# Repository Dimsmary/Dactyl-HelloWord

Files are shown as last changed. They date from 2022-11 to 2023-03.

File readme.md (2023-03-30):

# 引言

嗨，这是一个使用了瀚文HelloWord固件的Dactyl人体工程学键盘，其继承了瀚文键盘的基本功能（按键、RGB灯效），支持热插拔，并使用了Dactyl生成器所生成的外壳。

为了最大程度适配瀚文固件所产生的一些设计，导致本项目的复刻难度可能较高，详细情况将在后续内容提及。

# 致谢、参考项目

非常感谢键盘爱好者的无私奉献，下面是本项目继承、参考的项目：

- [peng-zhihui-HelloWord-Keyboard](https://github.com/peng-zhihui/HelloWord-Keyboard)

  瀚文键盘

- [ibnuda-dactyl-keboard](https://github.com/ibnuda/dactyl-keyboard)

  dactyl外壳生成器

- [yejianfengblue-dactyl-generator-demo](https://github.com/yejianfengblue/dactyl-generator-demo)

  dactyl外壳生成器在各参数下的demo

# 文件结构

- 3Dmodel

  该目录下存放了3D模型文件，其中包括了dactyl外壳生成器的json配置文件、OpenSCAD源文件、用于固定PCB的SolidWorks工程文件以及最终导出，能够直接进行3D打印的STL文件。

- Firmware

  该目录下存放了修改后的瀚文键盘固件工程文件、固件（release文件夹下）。

- PCB

  该目录下存放了使用LCEDA绘制的PCB原理图、Layout，以及能够直接用于PCB制造的Gerber文件。

# 构建指南

## 电路构建

本项目的PCB一共包括三块：轴板（Keyboard），主控板（LeftBoard）、扩展板（RightBoard）。

由于Dactyl的异形结构（每个轴都不在一个平面上），按键轴的安装并不能用一块PCB完成。在其他的Dactyl项目中，轴与轴之间的连接通过手工飞线实现。

### 轴板

但为了继承瀚文键盘的大部分功能，使用飞线的方案可能导致较大的飞线数量，故本项目采用了每个按键使用单独一块PCB的方案。每块PCB上焊有RGB灯珠、轴座以及FPC排线连接座，PCB之间以及与主控板的连接通过FPC软排线实现。

为了节省打板费用，我将25个按键PCB拼板到了一个10x10cm的PCB上。

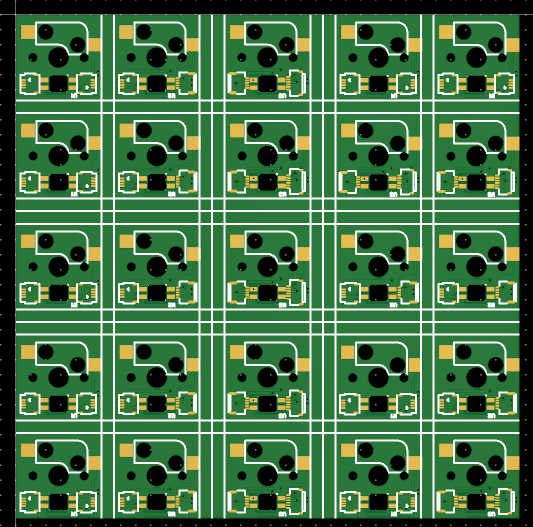
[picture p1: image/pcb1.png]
pcb1


注意，这25个按键PCB并不是一样的，而是分为了3号PCB、2号PCB以及1号PCB。

对于1号PCB，其右边的FPC连接座为6P，从上至下的线序为（KEY1/KEY2/KEY3/GND/DIN/5V），而左边的FPC连接座为5P，从上至下的线序为（KEY2/KEY3/GND/DOUT/5V）。右边的6P座直接与主控连接，负责获取RGB灯珠的电源、信号以及传递按键连接。左边的5P座与2号PCB的5P座连接，将RGB电源、信号传递以及按键连接线的中继。

对于2号PCB，其右边的FPC连接座为5P，即与1号PCB相连。左边的FPC连接座为4P，从上至下的线序为（KEY2/KEY3/GND/DOUT/5V），与3号PCB相连。

对于3号PCB，其右边4P座与2号相连，左边的4P座定义为（GND/DOUT/DOUT/GND），即将RGB灯珠的输出信号传回至主控板。

1、2、3号PCB构成一个按键PCB组，由于RGB灯珠的信号是逐级传递的，故每个PCB组的3号PCB需要传回主控板，主控板再走线将信号输出至下一个PCB组的RGB信号输入。

每个PCB单元可以沿着白线使用铁皮剪剪开获得独立的PCB。

注意1：建议先进行剪裁再进行焊接，如果先焊接在剪裁的话可能会导致焊接在PCB上的元件损坏。

注意2：轴板的焊接工作量巨大，如果经济实力允许，建议使用SMT服务。

注意3：4P座的排线连接方向是反的，但不影响使用，如在意，可自行调整。

### 主控板

主控板的电路完全参考瀚文键盘，在移位寄存器的数量上进行了删减。其上一共有四个连接器：RJ45（负责给扩展板提供电源和传递信号）、Type-C（连接电脑）、SWD（程序下载接口）、UART（预留接口，可进行瀚文键盘其他功能的扩展）。

主控板被安装在左手键盘。

### 扩展板

扩展板上仅有移位寄存器、连接座以及LDO，其与主控板的连接通过RJ45实现。

注意：在USB连接上电脑前，需要保证主控板和扩展版的连接通畅，如果两块板之间的连接断开的话，由于单片机缺少移位寄存器的回传信号，会导致按键误判（表现为随机输出按键信息至电脑）。

## 外壳构建

OpenSCAD文件夹：其内包括了Dactyl外壳的OpenSCAD源文件以及生成器的Json文件。将Json文件导入外壳生成器的网站可以加载我的设置并进行修改。

SolidWorks文件夹：其内包括了承载电路板的结构件。

STL文件夹：其内的STL文件可直接进行3D打印。

注意1：由于空间问题，承载电路板的结构件与外壳之间的卡口处需要打磨。

注意2：由于设计问题，两块电路板的底面需要是平整的，需要使用锉刀锉去凸起，否则无法安装仅承载电路板的结构件。

## 固件上传

通过STLINK或其他下载器，将Firmware>Release中的bin文件上传至STM32即可，若需要进行键位的修改，可自行编译HelloWord-keyborad-fw中的文件。

# 友情项目

这里记录了其他爱好者基于本项目进行改进的项目：

https://github.com/Byvm815/Dactyl-HelloWord

# 更新日志

2022-11-04：

readme基本完成，但还需要完善。

2022-03-30：

readme添加友情项目

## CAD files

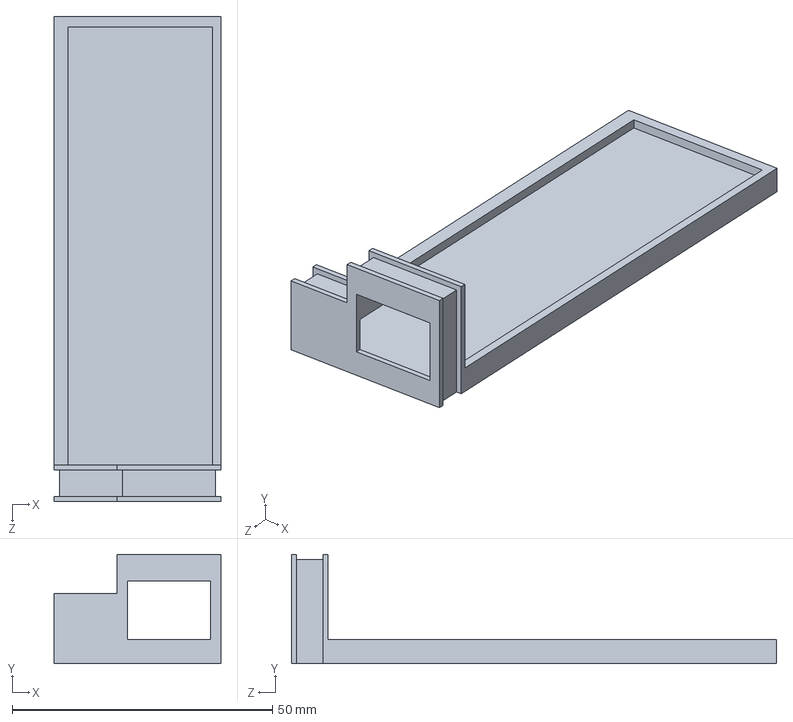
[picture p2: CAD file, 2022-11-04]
3Dmodel/SolidWorks/right_board_support.SLDPRT
32.0 x 21.0 x 93.1 mm

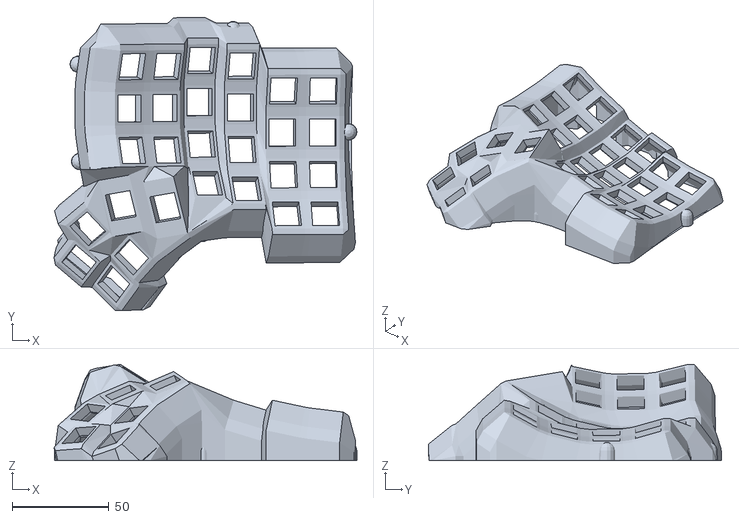
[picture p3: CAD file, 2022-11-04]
3Dmodel/STL/manuform-case-right-2022.08.30-12.28.57.stl
156.7 x 151.5 x 49.9

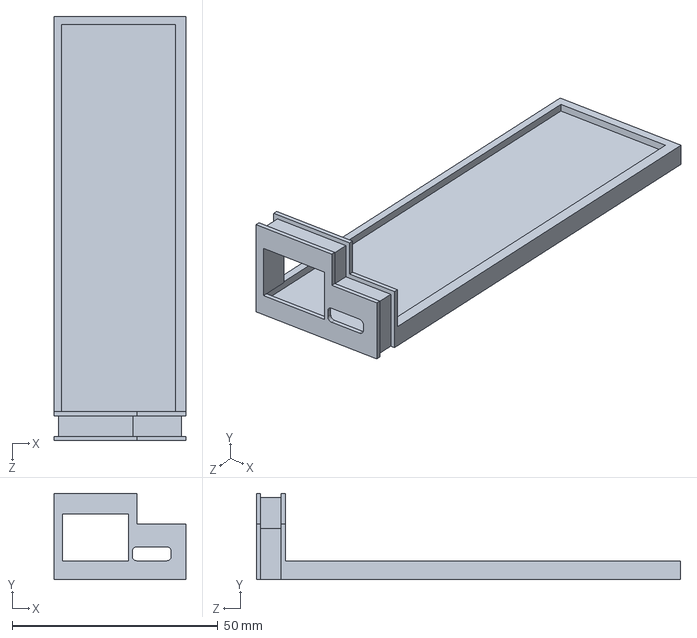
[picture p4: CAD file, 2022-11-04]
3Dmodel/SolidWorks/left_board_support.SLDPRT
32.0 x 21.0 x 103.1 mm

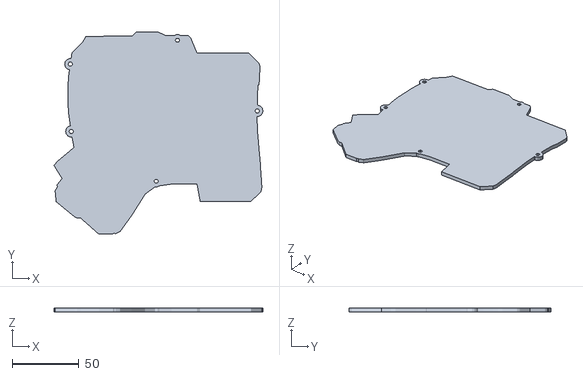
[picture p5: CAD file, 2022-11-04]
3Dmodel/STL/manuform-plate-right-2022.08.30-12.28.55.stl
156.4 x 151.4 x 3.00

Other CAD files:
3Dmodel/STL/manuform-case-left-2022.08.30-12.29.05.stl
3Dmodel/STL/manuform-plate-left-2022.08.30-12.29.03.stl
3Dmodel/OpenSCAD/manuform-case-left-2022.08.30-12.29.05.scad
3Dmodel/OpenSCAD/manuform-case-right-2022.08.30-12.28.57.scad
3Dmodel/OpenSCAD/manuform-plate-2022.08.30-12.28.55.scad
3Dmodel/OpenSCAD/manuform-plate-2022.08.30-12.29.03.scad
3Dmodel/STL/left_board_support.STL
3Dmodel/STL/right_board_support.STL

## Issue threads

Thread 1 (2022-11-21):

关于轴板在键盘外壳上的分布问题

A-new-b, 2022-11-21:
您好，我对您的键盘方案十分感兴趣，目前正在按照您提供的方案制作键盘，但我目前遇见了一个问题。

您提到了轴板有三种类型，分别为U1,U2,U3,对应4pin,5pin,6pin,在外壳上，我并不清楚单独的一个格子对应的是u1,u2还是u3,
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

我确实已经反复看过您的视频和立创文件，目前卡在了这一步，希望您能给我一个解答，感激不尽！

Dimsmary, 2022-11-21:
不好意思，轴板的连接比较复杂，文档还有待完善。
左手的轴板连接如图所示，如果有任何疑问欢迎继续提出。
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

Dimsmary, 2022-11-21:
不好意思，轴板的连接比较复杂，文档还有待完善。
左手的轴板连接如图所示，右手轴板排布基本相同，如果有任何疑问欢迎继续提出。
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

A-new-b, 2022-11-21:
非常感谢，我参照原理图和您的轴板后基本明白了

Closed 2022-11-21.

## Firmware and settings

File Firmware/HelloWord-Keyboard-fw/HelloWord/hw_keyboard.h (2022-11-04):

#ifndef HELLO_WORD_KEYBOARD_FW_HW_KEYBOARD_H
#define HELLO_WORD_KEYBOARD_FW_HW_KEYBOARD_H

#include "spi.h"


class HWKeyboard
{
public:
    explicit HWKeyboard(SPI_HandleTypeDef* _spi) :
        spiHandle(_spi)
    {
        scanBuffer = &spiBuffer[1];

        // Enable 74HC165 clock
        HAL_GPIO_WritePin(CE_GPIO_Port, CE_Pin, GPIO_PIN_RESET);
    }


    static const uint8_t IO_NUMBER = 11 * 8; // Used 11 pcs 74HC165
    static const uint8_t KEY_NUMBER = 82;
    static const uint8_t TOUCHPAD_NUMBER = 6;
    static const uint8_t LED_NUMBER = 104;
    static const uint8_t KEYMAP_NUM = 5;
    static const uint16_t KEY_REPORT_SIZE = 1 + 16;
    static const uint16_t RAW_REPORT_SIZE = 1 + 32;
    static const uint16_t HID_REPORT_SIZE = KEY_REPORT_SIZE + RAW_REPORT_SIZE;

    enum KeyCode_t : int16_t
    {
        /*------------------------- HID report data -------------------------*/
        LEFT_CTRL = -8, LEFT_SHIFT = -7, LEFT_ALT = -6, LEFT_GUI = -5,
        RIGHT_CTRL = -4, RIGHT_SHIFT = -3, RIGHT_ALT = -2, RIGHT_GUI = -1,

        RESERVED = 0, ERROR_ROLL_OVER, POST_FAIL, ERROR_UNDEFINED,
        A, B, C, D, E, F, G, H, I, J, K, L, M,
        N, O, P, Q, R, S, T, U, V, W, X, Y, Z,
        NUM_1/*1!*/, NUM_2/*2@*/, NUM_3/*3#*/, NUM_4/*4$*/, NUM_5/*5%*/,
        NUM_6/*6^*/, NUM_7/*7&*/, NUM_8/*8**/, NUM_9/*9(*/, NUM_0/*0)*/,
        ENTER, ESC, BACKSPACE, TAB, SPACE,
        MINUS/*-_*/, EQUAL/*=+*/, LEFT_U_BRACE/*[{*/, RIGHT_U_BRACE/*]}*/,
        BACKSLASH/*\|*/, NONE_US/**/, SEMI_COLON/*;:*/, QUOTE/*'"*/,
        GRAVE_ACCENT/*`~*/, COMMA/*,<*/, PERIOD/*.>*/, SLASH/*/?*/,
        CAP_LOCK, F1, F2, F3, F4, F5, F6, F7, F8, F9, F10, F11, F12,
        PRINT, SCROLL_LOCK, PAUSE, INSERT, HOME, PAGE_UP, DELETE, END, PAGE_DOWN,
        RIGHT_ARROW, LEFT_ARROW, DOWN_ARROW, UP_ARROW, PAD_NUM_LOCK,
        PAD_SLASH, PAD_ASTERISK, PAD_MINUS, PAD_PLUS, PAD_ENTER,
        PAD_NUM_1, PAD_NUM_2, PAD_NUM_3, PAD_NUM_4, PAD_NUM_5,
        PAD_NUM_6, PAD_NUM_7, PAD_NUM_8, PAD_NUM_9, PAD_NUM_0,
        PAD_PERIOD = 99, // followed with 20 bits 0, total 16 Bytes report data
        /*------------------------- HID report data -------------------------*/

//      /*-------------------------- Virtual keys ---------------------------*/
//      EXECUTE = 116,
//      HELP, MENU, SELECT, STOP, AGAIN, UNDO, CUT, COPY, PASTE, FIND, MUTE,
//      VOLUME_UP, VOLUME_DOWN,
//      /*-------------------------- Virtual keys ---------------------------*/

        /*--------------------------- Smart keys ----------------------------*/
        FN = 1000,
        TOUCH_BAR_1, TOUCH_BAR_2, TOUCH_BAR_3, TOUCH_BAR_4, TOUCH_BAR_5, TOUCH_BAR_6
        /*--------------------------- Smart keys ----------------------------*/
    };

    struct Color_t
    {
        uint8_t r;
        uint8_t g;
        uint8_t b;
    };

    enum SpiWs2812Byte_t : uint8_t
    {
        // This should be tuned considering WS2812b clock timing
        WS_HIGH = 0xFE,
        WS_LOW = 0xE0
    };


    uint8_t* ScanKeyStates();
    void ApplyDebounceFilter(uint32_t _filterTimeUs = 100);
    uint8_t* Remap(uint8_t _layer = 1);
    void SetRgbBuffer(uint8_t _keyId, Color_t _color);
    void SyncLights();
    bool FnPressed();
    uint8_t* GetHidReportBuffer(uint8_t _reportId = 0);


    int16_t keyMap[KEYMAP_NUM][IO_NUMBER] = {
        // The first layer, used for aligning 74HC165 IO pins to PCB key layout
        {0,1, 2, 3, 4, 5, 6, 7, 8, 9, 10,11,12,13,
                14, 15,16,17,18,19,20,21,22,23,24,25,26,27,28,
                29,30, 31, 32, 33, 34, 35, 36, 37, 38, 39, 40, 41, 42,
                43, 44, 45, 46, 47, 48, 49, 50, 51, 52, 53, 54, 55, 56,
                57, 58,59, 60, 61, 62, 63},

        // Other layer, used for mapping default key layout to custom layout
        {ESC, F1, F2, BACKSLASH, ENTER, LEFT_U_BRACE, RIGHT_U_BRACE, BACKSPACE, PERIOD, SLASH, RIGHT_SHIFT, N,M,COMMA,
            L, SEMI_COLON, QUOTE, H, J, K, O, P, MINUS, Y,U,I, NUM_9, NUM_0, EQUAL,
                NUM_6, NUM_7, NUM_8,E,R,T,Y,LEFT_ALT,SPACE,LEFT_GUI,ESC,C,V,B, LEFT_CTRL,
            Z, X,D,F,G,CAP_LOCK, A,S,E,R,T, TAB, Q,W,
            NUM_3, NUM_4, NUM_5,GRAVE_ACCENT, NUM_1, NUM_2,},

            {ESC, F1, F2, F3, F4, F5, F6, F7, F8, F9, F10, F11, F12, PAUSE,
            GRAVE_ACCENT, NUM_1, NUM_2, NUM_3, NUM_4, NUM_5, NUM_6, NUM_7, NUM_8, NUM_9, NUM_0, MINUS, EQUAL, BACKSPACE, INSERT,
            TAB, Q,W,E,R,T,Y,U,I,O,P,LEFT_U_BRACE, RIGHT_U_BRACE, BACKSLASH, DELETE,
            CAP_LOCK, A,S,D,F,G,H,J,K,L,SEMI_COLON, QUOTE, ENTER, PAGE_UP,
            LEFT_SHIFT, Z,X,C,V,B,}
    };

    volatile bool isRgbTxBusy{};
    uint8_t hidBuffer[HID_REPORT_SIZE]{};
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

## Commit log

2022-11-04 init commit
    [configurations.h, left_board_support.SLDPRT, left_board_support.STL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]
2022-11-06 PAP File update
    [PickAndPlace_PCB1_2022-11-06.xlsx, PickAndPlace_PCB2_2022-11-06.xlsx, PickAndPlace_PCB3_2022-11-06.xlsx]
